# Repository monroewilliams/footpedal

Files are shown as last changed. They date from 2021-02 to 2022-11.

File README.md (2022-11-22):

# README #

This is the hardware and case design for a widget I've built to interface generic foot switches (like those used to control guitar effects processors) to USB.

The device reports itself as either a USB HID gamepad with a configurable number of buttons, or as a keyboard which reports presses on F16, F17, etc. Switch between these modes by commenting/uncommenting the definition of `EMULATE_JOYSTICK` in footpedal.cpp.

The hardware is currently based around a Sparkfun Pro Micro (since that's what I had lying around):

https://www.sparkfun.com/products/12587

but it should be pretty trivial to adapt to other microcontrollers that have Arduino support in PlatformIO.

The code isn't too far off a generic "Gamepad" Arduino example that reports buttons and no hat switches or other axes, but it does have a couple of slightly interesting bits:

The `platformio.ini` file is set up to run `custom_config.py`, which changes the USB product identifier from the board's default to "Footpedals", which is slightly more user-friendly than the default "Sparkfun Pro Micro".

Configuration for the number and interpretation of buttons is done entirely through the contents of the `singlePins` and `triplePins` arrays. 
`triplePins` is set up to work with triple footswitches that interface through a 1/4" TRS plug, such as the [Digitech FS3X](https://www.digitech.com/foot-controllers/FS3X+3-Button+Footswitch.html) and similar units. These use a very simple circuit to multiplex 3 buttons over 2 signal wires. If you're connecting something like this, add the two pins you connect to the tip and ring connections of the jack to the `triplePins` array, and it will read all three switches out as buttons.

The `case.scad` file is an [OpenSCAD](https://www.openscad.org) model of a 3D-printable case that I created to hold a mini breadboard and a configurable number of 1/4" panel mount jacks. Changing `jack_count` in that file will expand the case to hold the number of jacks you choose. (If you set it below 2, there may not be room for the breadboard anymore.) `usb_h` and `usb_v` set the location of the hole for the USB jack, you may have to fiddle with the numbers to line it up with the plug on your breadboard/controller combo.

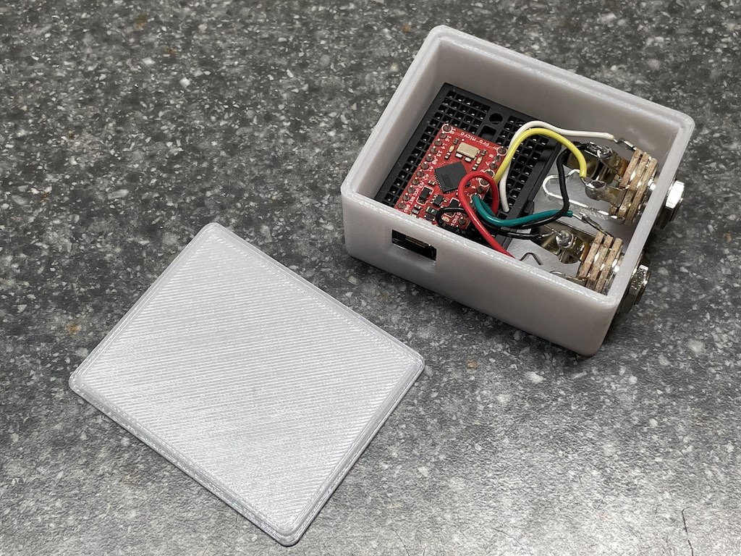
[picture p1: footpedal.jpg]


# BUILD #

I'm building this with PlatformIO/VSCode. Open the root directory of the repository directly with VSCode, and it should be ready to build.

I do my work on Mac OS X, so I don't know if there will be any issues using it on Windows or Linux.

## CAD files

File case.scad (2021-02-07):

jack_count = 2;
usb_h = 16.5;
usb_v = 14;

jack_width = 25;
jack_depth = 25;
interior_width = 35 + jack_depth + 3;
interior_length = jack_width * jack_count;
interior_height = jack_width;
wall_thickness = 3;

$fn=30;

module rcube(x, y, z, r)
{
    translate([r, r, 0])
    linear_extrude(height = abs(z))
    offset(r)
    square([x - (r * 2), y - (r * 2)]);
}

module jack()
{
    translate([wall_thickness + 25/2, wall_thickness, wall_thickness + (25/2)])
    rotate([-90, 0, 0])
    {
        translate([0, 0, -11])
        cylinder(d=10, h=12);
        cylinder(d=25, h=25);
    }
}

module usb()
{
    usbsize = 12.5;
    translate([
        -2,
        -usb_h + (usbsize / 2) + interior_width + wall_thickness - usbsize ,
        usb_v -  (usbsize / 2) + wall_thickness
    ])
    cube([usbsize, usbsize, usbsize]);
}

// case bottom
difference() 
{
    // outer body
    rcube(
        interior_length + (2 * wall_thickness), 
        interior_width + (2 * wall_thickness),
        interior_height + (1.5 * wall_thickness),
        wall_thickness);

//    // top cut for lid
    translate([wall_thickness/2, wall_thickness/2, interior_height + wall_thickness])
    rcube(
        interior_length + (wall_thickness), 
        interior_width + (wall_thickness),
        wall_thickness * 2,
        wall_thickness);

    // interior cut
    translate([wall_thickness, wall_thickness, wall_thickness])
    cube(size=[
        interior_length, 
        interior_width,
        interior_height + 2 * wall_thickness]);

    // jack cutouts
    for (i = [0:1:jack_count-1])
    {
        translate([i * jack_width, 0, 0])
        jack();
    }
    
    // USB cutout
    usb();

}

// Lid
translate([0, interior_width + wall_thickness * 4, 0])
union()
{
    rcube(
        interior_length + (wall_thickness * 2), 
        interior_width + (wall_thickness * 2),
        wall_thickness/2,
        wall_thickness);

    translate([wall_thickness / 2, wall_thickness / 2, 0])
    rcube(
        interior_length + wall_thickness, 
        interior_width + wall_thickness,
        wall_thickness,
        wall_thickness);
}

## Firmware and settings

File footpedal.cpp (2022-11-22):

// Pin assignments for polling.

// Each pair of pins in triplePins array is grouped together and read together to create one of 3 states, which are reported as 3 separate buttons:
// - first grounded
// - second grounded
// - both grounded
// (This matches the functionality of the Digitech FS3X pedal box, as well as several other three button effects foot pedals out there)
const int triplePins[] = { 2, 3 };

// Pins in this array are polled individually and reported as single buttons.
const int singlePins[] = { 4, 5 };

const unsigned char triplesCount = (sizeof(triplePins) / sizeof(triplePins[0]));
const unsigned char singlesCount = (sizeof(singlePins) / sizeof(singlePins[0]));
const int buttonCount = (triplesCount * 3) / 2 + singlesCount;

// Uncomment this to emulate joystick buttons.
// Comment it out to emulate keyboard keys (F16 and up).
// #define EMULATE_JOYSTICK 1

#ifdef EMULATE_JOYSTICK
#include <Joystick.h>
// USB descriptor for a gamepad with nothing but buttons.
Joystick_ Joystick
(
		JOYSTICK_DEFAULT_REPORT_ID, // hidReportId
		JOYSTICK_TYPE_GAMEPAD, // joystickType
    buttonCount, // buttonCount
		0, // hatSwitchCount
		false, // includeXAxis
		false, // includeYAxis
		false, // includeZAxis
		false, // includeRxAxis
		false, // includeRyAxis
		false, // includeRzAxis
		false, // includeRudder
		false, // includeThrottle
		false, // includeAccelerator
		false, // includeBrake
		false // includeSteering
);

#else
// USB descriptor for a keyboard. We'll assign keys starting at KEY_F16
#include <Keyboard.h>

#endif

int lastButtonState[buttonCount];

#define SERIAL_DEBUG 0

#if SERIAL_DEBUG
	#define DebugLog(...) Serial.print(__VA_ARGS__)
	#define DebugLogln(...) Serial.println(__VA_ARGS__)
#else
	#define DebugLog(...)
	#define DebugLogln(...)
#endif

void setup() {
#if SERIAL_DEBUG
  Serial.begin(115200);
#endif

  // Initialize Button Pins
  for (uint8_t i = 0; i < triplesCount; i++)
  {
    pinMode(triplePins[i], INPUT_PULLUP);
  }
  for (uint8_t i = 0; i < singlesCount; i++)
  {
    pinMode(singlePins[i], INPUT_PULLUP);
  }
  
  // Set up initial button state
  for (uint8_t i = 0; i < buttonCount; i++)
  {
    lastButtonState[i] = 0;
  }

#ifdef EMULATE_JOYSTICK
  // Initialize Joystick Library
  Joystick.begin();
#else
  Keyboard.begin();
#endif

}

void loop() {
  int button = 0;

  // Read triplePins pin values by pairs
  for (uint8_t i = 0; i < triplesCount; i += 2)
  {
    int current[3] = {0, 0, 0};
    current[0] = !digitalRead(triplePins[i]);
    current[1] = !digitalRead(triplePins[i + 1]);

    DebugLog(F("("));
    DebugLog(triplePins[i]);
    DebugLog(F(", "));
    DebugLog(triplePins[i + 1]);
    DebugLog(F(") -> ("));
    DebugLog(current[0]);
    DebugLog(F(", "));
    DebugLog(current[1]);
    DebugLog(")  ");

    if (current[0] && current[1])
    {
        current[0] = 0;
        current[1] = 0;
        current[2] = 1;
    }

    for (int j = 0; j < 3; j++)
    {
        if (lastButtonState[button] != current[j])
        {
#ifdef EMULATE_JOYSTICK
          Joystick.setButton(button, current[j]);
#else
          if (current[j]) {
            Keyboard.press(KEY_F16 + button);
          } else {
            Keyboard.release(KEY_F16 + button);
          }
#endif
          lastButtonState[button] = current[j];
        }
        button++;
    }

  }

  // Read singlePins pins individually
  for (uint8_t i = 0; i < singlesCount; i++)
  {
    int current = !digitalRead(singlePins[i]);
    
    DebugLog(singlePins[i]);
    DebugLog(F(" -> "));
    DebugLog(current);
    DebugLog(F("  "));

    if (lastButtonState[button] != current)
    {
#ifdef EMULATE_JOYSTICK
      Joystick.setButton(button, current);
#else
          if (current) {
            Keyboard.press(KEY_F16 + button);
          } else {
            Keyboard.release(KEY_F16 + button);
          }
#endif
      lastButtonState[button] = current;
    }
    button++;
  }

  DebugLogln("");

  delay(10);
}
